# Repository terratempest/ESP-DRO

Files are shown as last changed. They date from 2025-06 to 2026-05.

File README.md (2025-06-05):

ESP-DRO

This is a digital readout (DRO) program for ESP32 powered TFT/Touch displays, designed for lathes (or mills) using TTL quadrature glass scales and a 7" Sunton touchscreen (800x480 with GT911 touch).
This is coded in C++ and uses LVGL for the UI. Designed this mainly for my lathe where it's just handling 2 axes but code is modular and can be setup for additional axes provided you have enough free pins on your board to wire them up. 

Kind of rough around the edges and a bit of a work in progress. Testing this out myself so if you end up trying this let me know if you have any feedback!



What It Does:

* Reads multiple glass scale/TTL encoders in real-time (configurable axes)
* Shows all positions on a touchscreen DRO interface
* Stores global & per tool offsets
* Toggle between mm/inch, radius/diameter, incremental/absolute positioning
* All calibration, inversion, and tool data are persistent via NVS

Hardware Required

* ESP32-S3 powered LCD / Touch dev board (must have PSRAM) (RGB, GT911 touch)
* Linear scales with TTL quadrature output (5V)

Setup (Quick Start)
1. Install VSCode.
2. Install & configure ESP-IDF extension.
3. Clone Repository.
4. Open repository folder in VSCode.
4. Hardware Config
    
    Edit config.h to match your hardware:
    
        const AxisConfig AXES[] = {
            {"x", 17, 11, 5.0f}, // {name, pinA, pinB, resolution_um}
            {"z", 12, 13, 5.0f}, // add or remove axes as needed
        };
    
    Check all LCD/touch/encoder pins, adjust as needed for your board and wiring.
    Should work out of the box for the Sunton ESP32-S3 7" 800*480 TN Display with Touch

5. Build and Flash

Using the DRO

* All axes show up automatically.
* Tap the gear icon for calibration (set um/step and invert per axis).
* Use the tool dropdown to add, remove, or rename tools. Each tool stores unique offsets configurable with the TLO button per axis.
* Tap "IN" to switch between mm/inch, "DIA" for radius/diameter mode (only affects first axis).
* Tap ABS to toggle between incremental / absolute positioning. Incremental lets you use a temporary zero offset without effecting absolute position.
* All values are stored in flash and restored on reboot.

Customizing

* To add axes: Edit the AXES[] array in config.h and wire up more encoders.
* Change CONFIG_MAX_TOOLS if you need more tool slots.
* Everything else is in the UI—no code changes needed for common settings.

Structure

    main.cpp: Hardware setup and main loop

    config.h: All machine/display pin assignments and settings

    dro_axis.*: Handles encoder reading and axis state

    tool_manager.*: Tool storage and logic

    ui_manager.*, mainScreen.h: LVGL UI and event handling

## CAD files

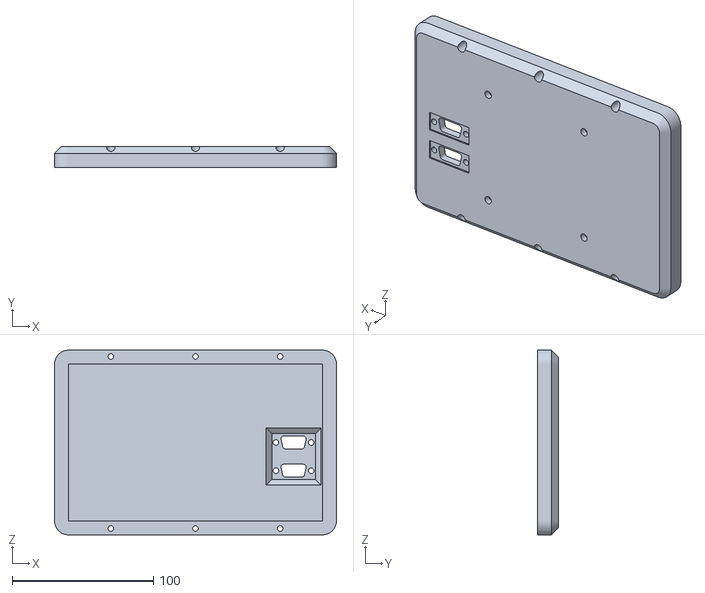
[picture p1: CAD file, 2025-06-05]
3D Prints/Display Frame Back.stl
200.0 x 15.0 x 131.0

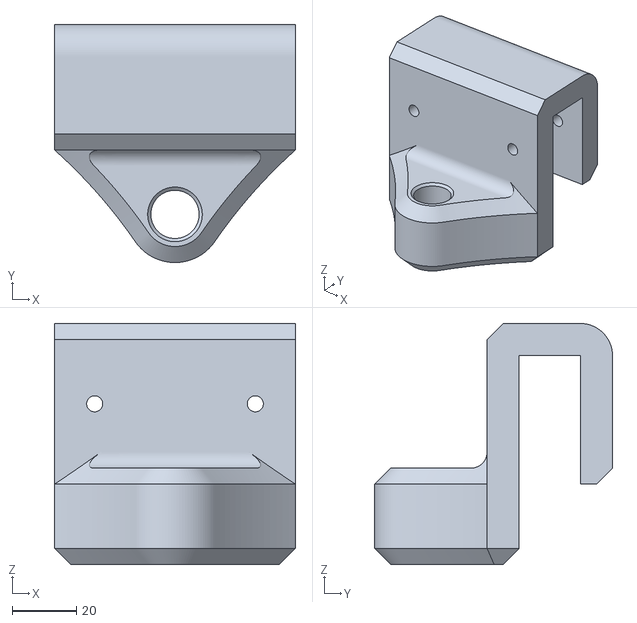
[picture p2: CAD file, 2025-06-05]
3D Prints/Screen Mount Hook.stl
75.0 x 74.1 x 75.0

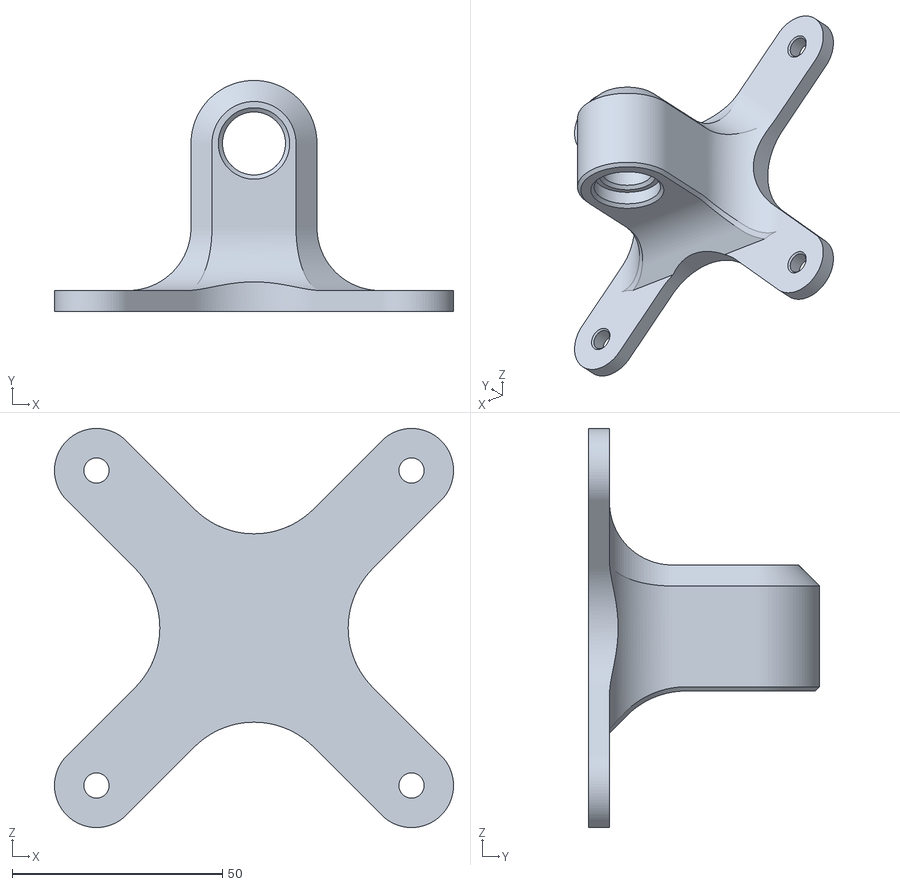
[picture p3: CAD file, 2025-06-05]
3D Prints/Screen Mount.stl
95.0 x 55.0 x 95.0

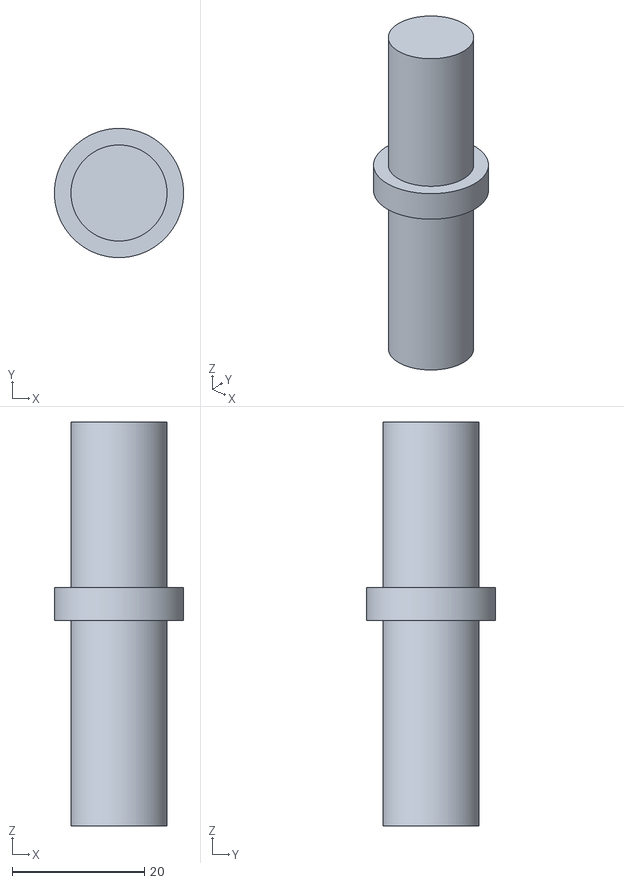
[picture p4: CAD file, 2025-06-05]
3D Prints/Screen Mount Pin.stl
19.5 x 19.5 x 61.0

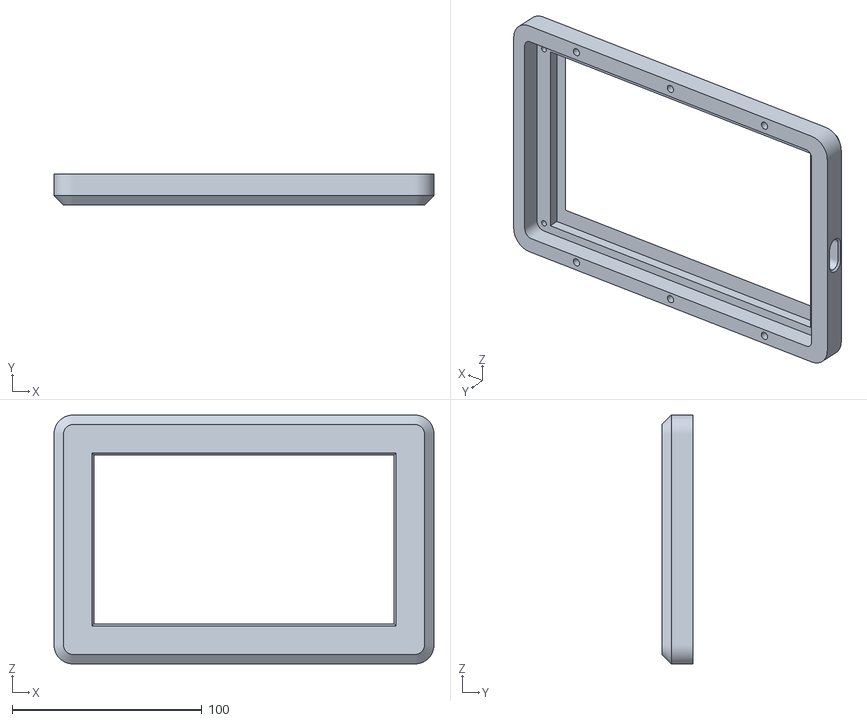
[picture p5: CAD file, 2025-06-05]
3D Prints/Display Frame Face.stl
200.0 x 16.4 x 131.0

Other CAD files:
3D Prints/ESP_DRO_DISPLAY_ENCLOSURE.f3d

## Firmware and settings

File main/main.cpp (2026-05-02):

#include "config.h"

// Core modules
#include "dro_axis.h"
#include "tool_manager.h"
#include "preferences_wrapper.h"
#include "app_display.h"

// UI
#include "ui_manager.h"

// LVGL
extern "C" {
    #include <lvgl.h>
}

#include "esp_log.h"
#include "esp_check.h"
#include "freertos/FreeRTOS.h"
#include "freertos/task.h"
#include "esp_timer.h"
#include "nvs_flash.h"
#include <string>
#include <iostream>
#include <driver/gpio.h>

// ------------ Hardware/Global Objects ------------

DroAxis DROAxes[AXES_COUNT];

PreferencesWrapper prefsWrapper(NVS_NAMESPACE);
ToolManager toolManager(prefsWrapper);

UIManager* uiManager = nullptr;

// Forward: LVGL tick glue
void lv_tick_handler(void* arg);

// ------------- Main Entry Point -------------

extern "C" void app_main() {
    // Logging
    esp_log_level_set("*", ESP_LOG_INFO);
    ESP_LOGI("MAIN", "DRO Firmware Starting...");

    esp_err_t nvsErr = nvs_flash_init();
    if (nvsErr == ESP_ERR_NVS_NO_FREE_PAGES || nvsErr == ESP_ERR_NVS_NEW_VERSION_FOUND) {
        ESP_ERROR_CHECK(nvs_flash_erase());
        nvsErr = nvs_flash_init();
    }
    ESP_ERROR_CHECK(nvsErr);
    prefsWrapper.begin();
    toolManager.loadTools();

    // Setup Axes
    // In app_main, replace the axis init loop:
    for (int i = 0; i < AXES_COUNT; ++i) {
        DROAxes[i].init(
            AXES[i].name,
            AXES[i].pinA,
            AXES[i].pinB,
            AXES[i].resolution_um,
            i
        );
        DROAxes[i].setStepUm(prefsWrapper.getFloat(std::string(DROAxes[i].name) + "_calib", AXES[i].resolution_um));
        DROAxes[i].setInvert(prefsWrapper.getBool(std::string(DROAxes[i].name) + "_invert", false));
        DROAxes[i].begin();
    }

    // LVGL init
    lv_init();
    app_display_init();

    // Setup UI
    uiManager = new UIManager(toolManager, DROAxes, prefsWrapper); 
    uiManager->init();

    // Set up LVGL tick (every 5ms) using esp_timer
    const esp_timer_create_args_t lvgl_tick_timer_args = {
        .callback = &lv_tick_handler,
        .arg = nullptr,
        .dispatch_method = ESP_TIMER_TASK,
        .name = "lv_tick"
    };
    esp_timer_handle_t lvgl_tick_timer;
    esp_timer_create(&lvgl_tick_timer_args, &lvgl_tick_timer);
    esp_timer_start_periodic(lvgl_tick_timer, 5000); // 5000us = 5ms

    ESP_LOGI("MAIN", "Setup complete!");

    uint32_t lastUiUpdateMs = 0;

    // Main loop (run forever)
    while (1) {
        lv_timer_handler(); // Handles all LVGL tasks
        vTaskDelay(pdMS_TO_TICKS(5)); // 5ms delay

        uint32_t nowMs = static_cast<uint32_t>(esp_timer_get_time() / 1000ULL);
        if (uiManager && nowMs - lastUiUpdateMs >= 33) {
            uiManager->updateDisplay();
            lastUiUpdateMs = nowMs;
        }

    }
}

// LVGL tick handler for periodic timer
void lv_tick_handler(void* arg) {
    lv_tick_inc(5);
}

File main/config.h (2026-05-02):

#pragma once

//----------------------------------------
// MACHINE/PROJECT CONFIGURATION
//----------------------------------------

// Axis/Encoder config
typedef struct { 
    const char* name;
    int   pinA;
    int   pinB;
    float resolution_um; // axis-specific resolution in um/pulse
} AxisConfig;

// Config for linear scales
const AxisConfig AXES[] = {
    // {name, pinA, pinB, resolution, toggle (optional)}
    {"x", 17, 11, 5.0f},
    //{"y", -1, -1, 5.0f}, // Uncomment for 3-axis
    {"z", 12, 13, 5.0f}, 
    // Add more axis as required
};
#define AXES_COUNT (sizeof(AXES)/sizeof(AXES[0])) // Number of axes defined

// PCNT overflow limits — 16-bit signed hardware counter
// Set well within ±32767 to give ISR time to fire
#define PCNT_H_LIM_VAL  20000
#define PCNT_L_LIM_VAL -20000

// Number of tools supported (for array allocation)
#define CONFIG_MAX_TOOLS 50

// Feature toggles (set to 1/0) // TODO: Implement logic to turn on/off in UI
#define ENABLE_DIAMETER_MODE   1 // Only applies to first defined axis 0
#define ENABLE_METRIC_TOGGLE   1
#define ENABLE_TOOL_MANAGEMENT 1

//----------------------------------------
// PREFERENCES STORAGE
//----------------------------------------
#define NVS_NAMESPACE "settings"
#define NVS_VERSION   1 

//----------------------------------------
// LOGGING
//----------------------------------------
#define DEFAULT_LOG_LEVEL      LOG_INFO 

//----------------------------------------
// DISPLAY & TOUCH
//----------------------------------------

// UI/TFT/LCD config (adjust for your display)
#define LCD_H_RES  800
#define LCD_V_RES  480

// Pixel clock
#define LCD_PIXEL_CLOCK_HZ  12500000U

// Data lines
#define DATA_GPIOS      {15, 7, 6, 5, 4, 9, 46, 3, 8, 16, 1, 14, 21, 47, 48, 45}

// Board pin mapping
#define LCD_PIN_HSYNC    GPIO_NUM_39
#define LCD_PIN_VSYNC    GPIO_NUM_40
#define LCD_PIN_DE       GPIO_NUM_41
#define LCD_PIN_PCLK     GPIO_NUM_42
#define LCD_PIN_BK_LIGHT GPIO_NUM_2

#define TOUCH_RST        GPIO_NUM_38
#define TOUCH_INT        GPIO_NUM_18
#define TOUCH_I2C_SDA    GPIO_NUM_19
#define TOUCH_I2C_SCL    GPIO_NUM_20
#define TOUCH_I2C_NUM    I2C_NUM_0
#define TOUCH_I2C_ADDR   0x5D  // GT911 Address for your hardware

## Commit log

2025-06-05 Added 3d Printed Screen Frame
    [Display Frame Back.stl, Display Frame Face.stl, ESP_DRO_DISPLAY_ENCLOSURE.f3d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]
2026-05-02 cleaned up depreciated driver usage
